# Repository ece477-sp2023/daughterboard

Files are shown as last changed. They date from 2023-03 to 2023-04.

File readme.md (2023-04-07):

# Things to change for v3

-   mosfet rotation
-   bulk capacitor on 2.5V plane
-   bulk capacitors directly on all regulator outputs
-   ftdi analog power from 5V
-   1.1V slow start from 3vi, not 3v3

# want to have

-   crystal for fpga?
-   crystal for ftdi?
    -   only if needed
-   indicator LEDs?
    -   power
    -   usb

# make sure before starting v3

-   ftdi chip works
    -   if not, have easy way to program flash

# notes for v3

-   8 layer board might give more space on top
-   don't need 1v1 slow start connected to both 3v3 and 2v5, just use 3v3
-   look at regulator stock for 5->3, don't know if footprint chosen is common / available

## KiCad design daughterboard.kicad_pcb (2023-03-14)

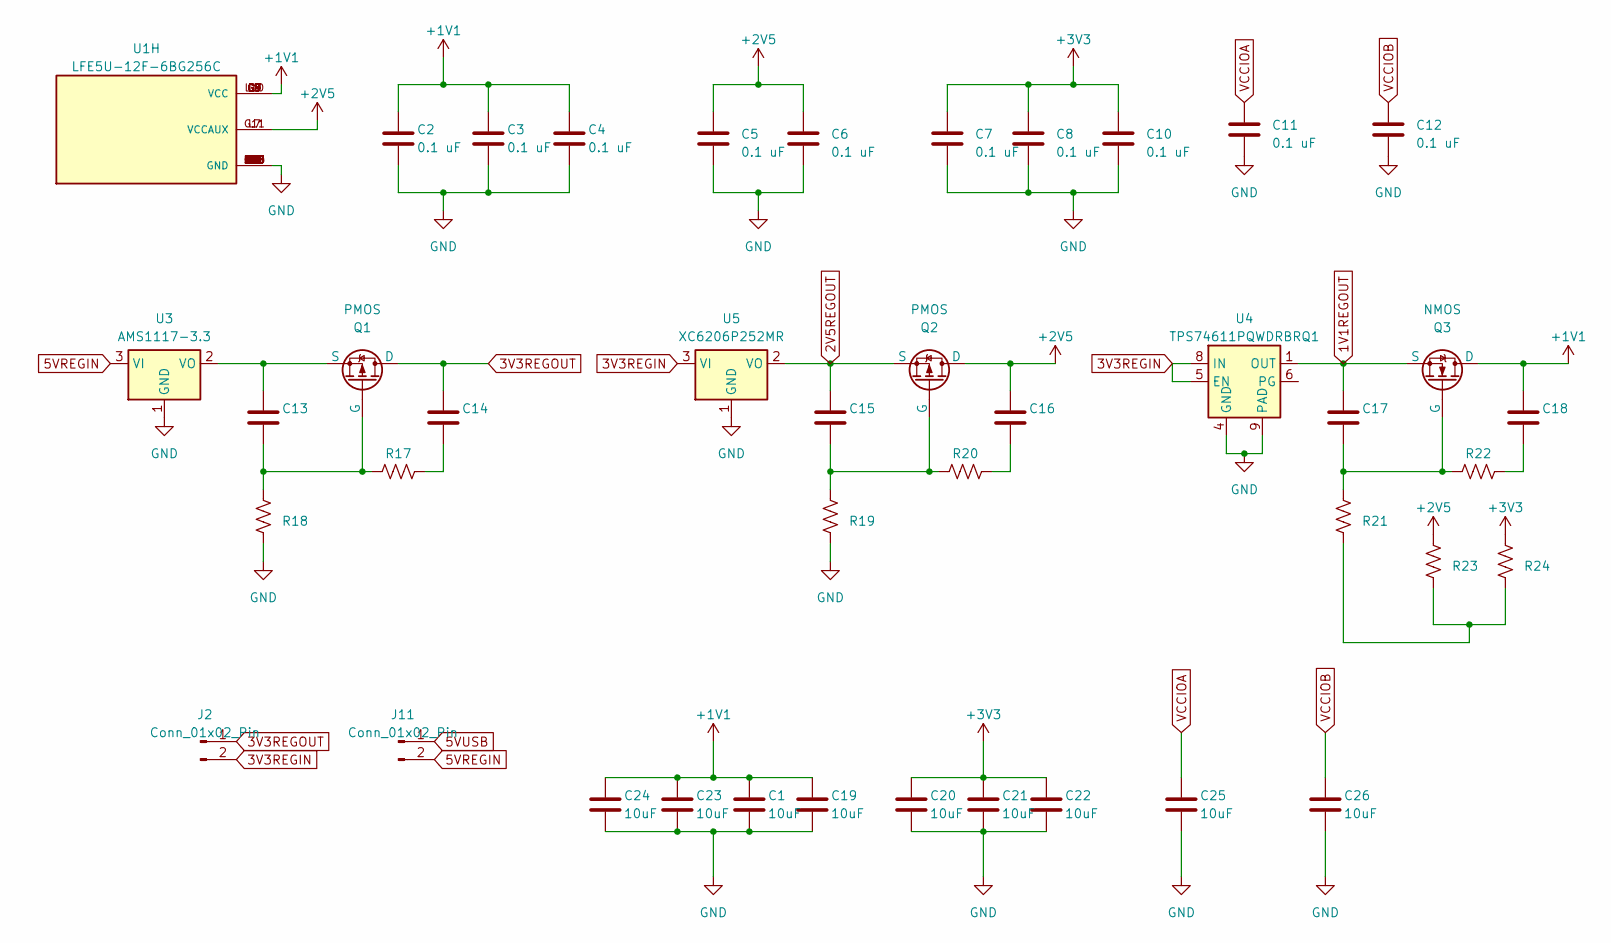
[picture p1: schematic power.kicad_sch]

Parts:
C1, C19, C20, C21, C22, C23, C24, C25, C26: 10uF; C_0805_2012Metric
C2, C3, C4, C5, C6, C7, C8, C10, C11, C12: 0.1 uF; C_0402_1005Metric
C13, C14, C15, C16, C17, C18: C_0805_2012Metric
J2, J11: Conn_01x02_Pin; PinHeader_1x02_P2.54mm_Vertical
Q1, Q2: PMOS; SOT-23-3
Q3: NMOS; SOT-23-3
R17, R18, R19, R20, R21, R22, R23, R24: R_0805_2012Metric
U1: LFE5U-12F-6BG256C; BGA256C80P16X16_1400X1400X170; PARTREV 2.0
U3: AMS1117-3.3; SOT-89-3
U4: TPS74611PQWDRBRQ1; Texas_S-PVSON-N8
U5: XC6206P252MR; SOT-23-3

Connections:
1V1REGOUT: C17.1, Q3.3 (S), U4.1 (OUT)
2V5REGOUT: C15.1, Q2.3 (S), U5.2 (VO)
3V3REGIN: J2.2, U4.5 (EN), U4.8 (IN), U5.3 (VI); also elsewhere on the board
3V3REGOUT: C14.1, J2.1, Q1.1 (D); also elsewhere on the board
5VREGIN: J11.2, U3.3 (VI); also elsewhere on the board
5VUSB: J11.1; also elsewhere on the board
+2V5: C5.1, C6.1, C16.1, Q2.1 (D), R23.2, U1.G11 (VCCAUX), U1.L7 (VCCAUX); also elsewhere on the board
GND: C1.2, C2.2, C3.2, C4.2, C5.2, C6.2, C7.2, C8.2, C10.2, C11.2, C12.2, C19.2, C20.2, C21.2, C22.2, C23.2, C24.2, C25.2, C26.2, R18.1, R19.1, U1.A1 (GND), U1.A16 (GND), U1.D2 (GND), U1.D15 (GND), U1.F8 (GND), U1.F9 (GND), U1.G8 (GND), U1.G10 (GND), U1.H1 (GND), U1.H8 (GND), U1.H9 (GND), U1.H10 (GND), U1.H16 (GND), U1.J8 (GND), U1.J9 (GND), U1.J10 (GND), U1.K6 (GND), U1.K7 (GND), U1.K8 (GND), U1.K9 (GND), U1.K10 (GND), U1.N2 (GND), U1.N15 (GND), U1.T1 (GND), U1.T5 (GND), U1.T12 (GND), U1.T16 (GND), U3.1 (GND), U4.4 (GND), U4.9 (PAD), U5.1 (GND); also elsewhere on the board
unnamed: C14.2, R17.1
unnamed: C16.2, R20.1
unnamed: C18.2, R22.1
unnamed: C13.2, Q1.2 (G), R17.2, R18.2
unnamed: C13.1, Q1.3 (S), U3.2 (VO)
unnamed: C15.2, Q2.2 (G), R19.2, R20.2
unnamed: C17.2, Q3.2 (G), R21.2, R22.2
unnamed: R21.1, R23.1, R24.1
VCCIOA: C11.1, C25.1; also elsewhere on the board
VCCIOB: C12.1, C26.1; also elsewhere on the board

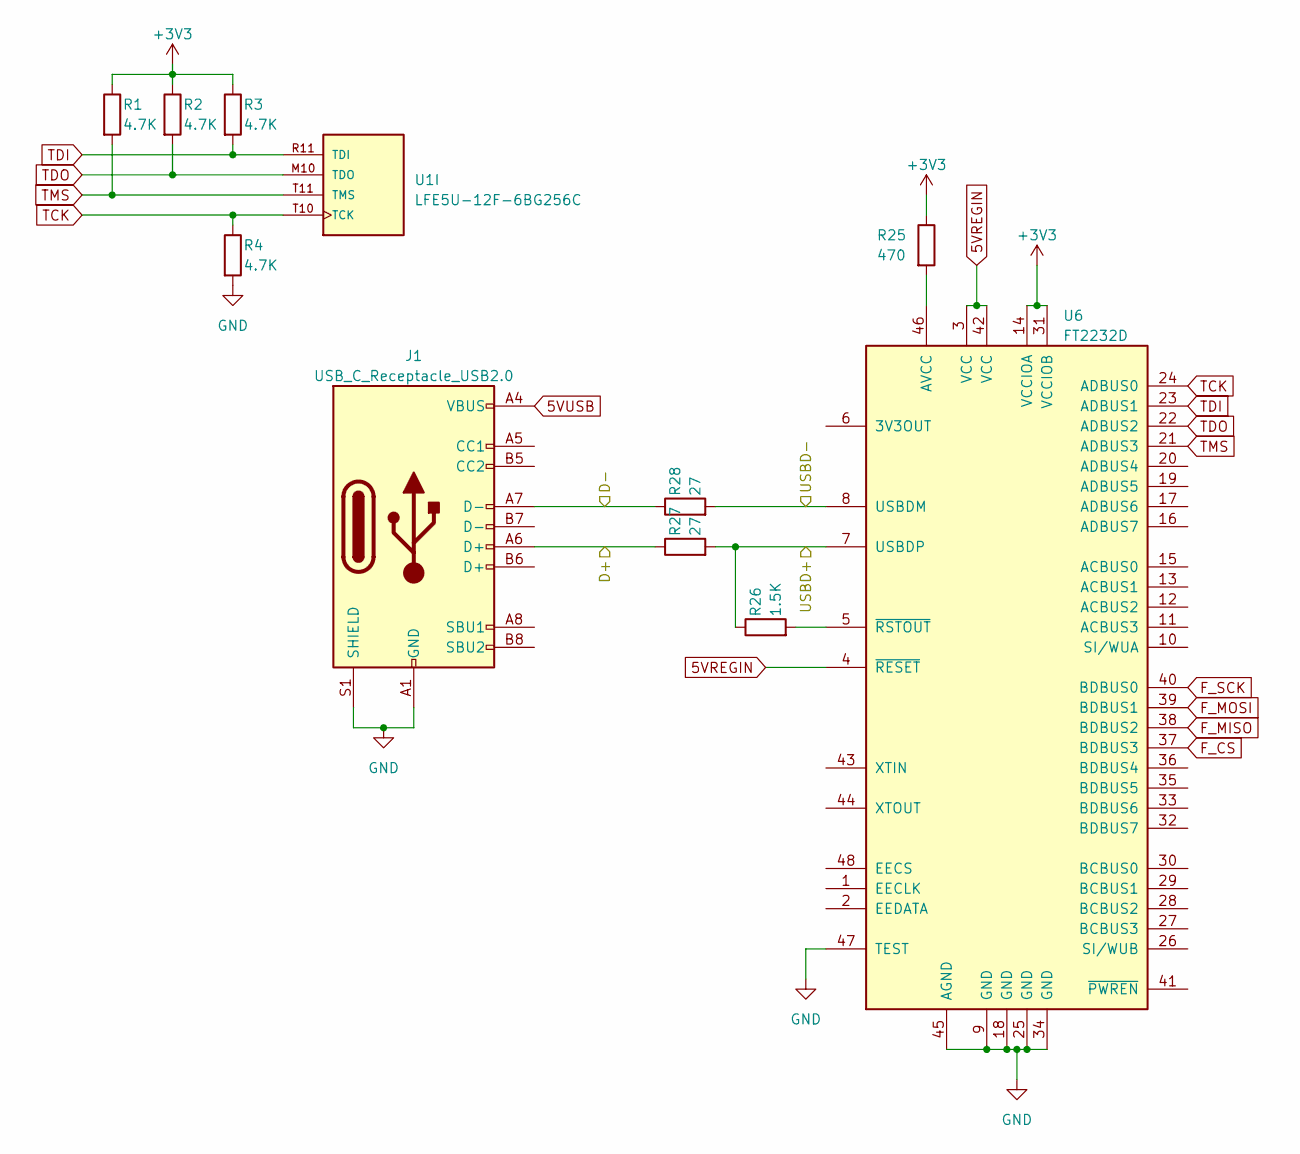
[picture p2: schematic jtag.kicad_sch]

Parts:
J1: USB_C_Receptacle_USB2.0; USB_C_GCT4105
R1, R2, R3, R4: 4.7K; R_0603_1608Metric
R25: 470; R_0603_1608Metric
R26: 1.5K; R_0603_1608Metric
R27, R28: 27; R_0603_1608Metric
U1: LFE5U-12F-6BG256C; BGA256C80P16X16_1400X1400X170; PARTREV 2.0
U6: FT2232D; LQFP-48_7x7mm_P0.5mm

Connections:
5VREGIN: U6.3 (VCC), U6.4 (~RESET), U6.42 (VCC); also elsewhere on the board
5VUSB: J1.A4 (VBUS), J1.A9 (VBUS), J1.B4 (VBUS), J1.B9 (VBUS); also elsewhere on the board
/JTAG/D+: J1.A6 (D+), R27.1
/JTAG/D-: J1.A7 (D-), R28.1
/JTAG/USBD+: R26.1, R27.2, U6.7 (USBDP)
/JTAG/USBD-: R28.2, U6.8 (USBDM)
F_CS: U6.37 (BDBUS3); also elsewhere on the board
F_MISO: U6.38 (BDBUS2); also elsewhere on the board
F_MOSI: U6.39 (BDBUS1); also elsewhere on the board
F_SCK: U6.40 (BDBUS0); also elsewhere on the board
GND: J1.A1 (GND), J1.A12 (GND), J1.B1 (GND), J1.B12 (GND), J1.S1 (SHIELD), R4.2, U6.9 (GND), U6.18 (GND), U6.25 (GND), U6.34 (GND), U6.45 (AGND), U6.47 (TEST); also elsewhere on the board
unnamed: R25.2, U6.46 (AVCC)
unnamed: R26.2, U6.5 (~RSTOUT)
TCK: R4.1, U1.T10 (TCK), U6.24 (ADBUS0); also elsewhere on the board
TDI: R3.2, U1.R11 (TDI), U6.23 (ADBUS1); also elsewhere on the board
TDO: R2.2, U1.M10 (TDO), U6.22 (ADBUS2); also elsewhere on the board
TMS: R1.2, U1.T11 (TMS), U6.21 (ADBUS3); also elsewhere on the board

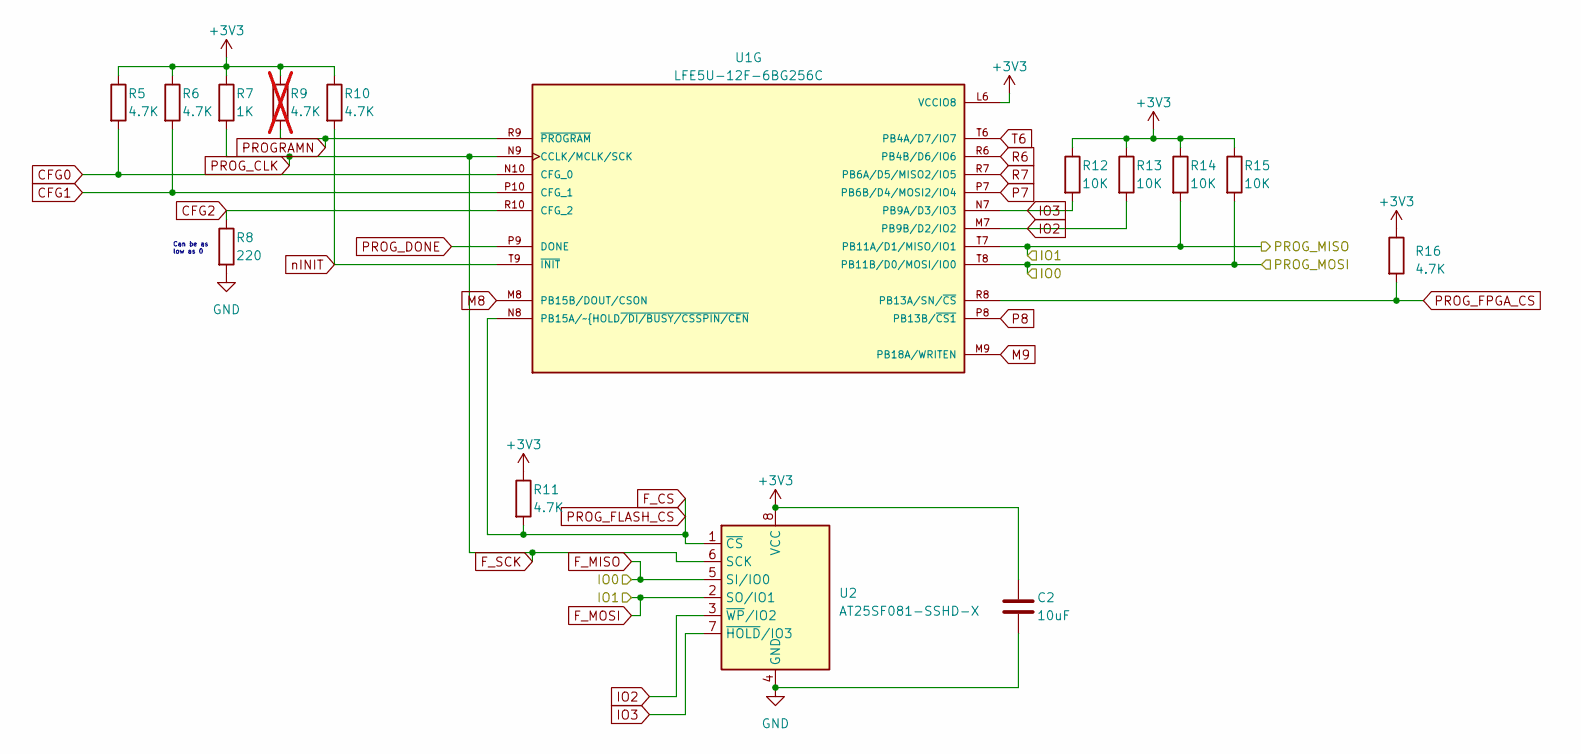
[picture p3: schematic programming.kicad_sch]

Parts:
C2: 10uF; C_0805_2012Metric
R5, R6, R10, R11, R16: 4.7K; R_0603_1608Metric
R7: 1K; R_0603_1608Metric
R8: 220; R_0603_1608Metric
R9: 4.7K; R_0603_1608Metric; not fitted
R12, R13, R14, R15: 10K; R_0603_1608Metric
U1: LFE5U-12F-6BG256C; BGA256C80P16X16_1400X1400X170; PARTREV 2.0
U2: AT25SF081-SSHD-X; SOIC-8_3.9x4.9mm_P1.27mm

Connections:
CFG0: R5.2, U1.N10 (CFG_0); also elsewhere on the board
CFG1: R6.2, U1.P10 (CFG_1); also elsewhere on the board
CFG2: R8.1, U1.R10 (CFG_2); also elsewhere on the board
F_CS: R11.2, U1.N8 (PB15A/~HOLD~{/DI/BUSY/CSSPIN/CEN), U2.1 (~CS); also elsewhere on the board
F_MISO: R15.2, U1.T8 (PB11B/D0/MOSI/IO0), U2.5 (SI/IO0); also elsewhere on the board
F_MOSI: R14.2, U1.T7 (PB11A/D1/MISO/IO1), U2.2 (SO/IO1); also elsewhere on the board
F_SCK: R7.2, U1.N9 (CCLK/MCLK/SCK), U2.6 (SCK); also elsewhere on the board
GND: C2.2, R8.2, U2.4 (GND); also elsewhere on the board
IO2: R13.2, U1.M7 (PB9B/D2/IO2), U2.3 (~WP/IO2); also elsewhere on the board
IO3: R12.2, U1.N7 (PB9A/D3/IO3), U2.7 (~HOLD/IO3); also elsewhere on the board
M8: U1.M8 (PB15B/DOUT/CSON); also elsewhere on the board
M9: U1.M9 (PB18A/WRITEN); also elsewhere on the board
P7: U1.P7 (PB6B/D4/MOSI2/IO4); also elsewhere on the board
P8: U1.P8 (PB13B/~CS1); also elsewhere on the board
PROGRAMN: R9.2, U1.R9 (~PROGRAM); also elsewhere on the board
PROG_DONE: U1.P9 (DONE); also elsewhere on the board
PROG_FPGA_CS: R16.2, U1.R8 (PB13A/SN/~CS); also elsewhere on the board
R6: U1.R6 (PB4B/D6/IO6); also elsewhere on the board
R7: U1.R7 (PB6A/D5/MISO2/IO5); also elsewhere on the board
T6: U1.T6 (PB4A/D7/IO7); also elsewhere on the board
nINIT: R10.2, U1.T9 (~INIT); also elsewhere on the board

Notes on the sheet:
Can be as low as 0

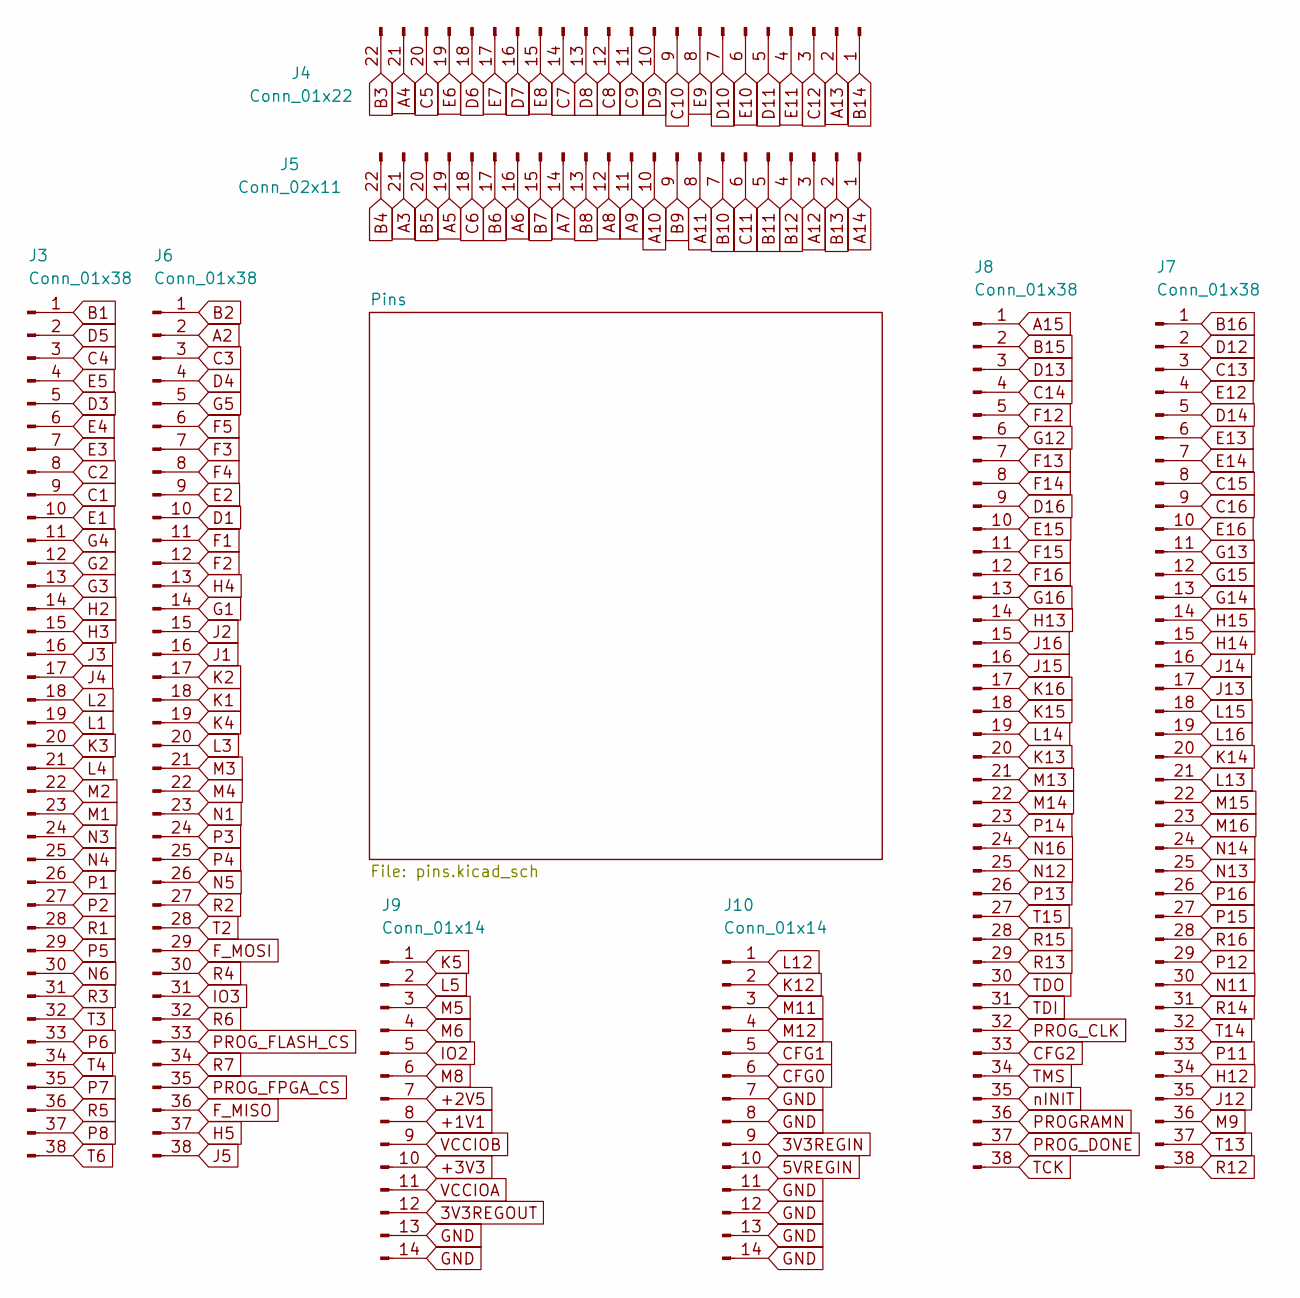
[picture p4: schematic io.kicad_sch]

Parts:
J3, J7: Conn_01x38; PinHeader_1x38_P1.27mm_Vertical
J4: Conn_01x22; PinHeader_1x22_P1.27mm_Vertical
J5: Conn_02x11; PinHeader_2x11_P2.54mm_Vertical
J6, J8: Conn_01x38; PinHeader_2x19_P2.54mm_Vertical
J9, J10: Conn_01x14; PinHeader_2x07_P2.54mm_Vertical

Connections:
3V3REGIN: J10.9; also elsewhere on the board
3V3REGOUT: J9.12; also elsewhere on the board
5VREGIN: J10.10; also elsewhere on the board
+2V5: J9.7; also elsewhere on the board
A2: J6.2; also elsewhere on the board
A3: J5.21; also elsewhere on the board
A4: J4.21; also elsewhere on the board
A5: J5.19; also elsewhere on the board
A6: J5.16; also elsewhere on the board
A7: J5.14; also elsewhere on the board
A8: J5.12; also elsewhere on the board
A9: J5.11; also elsewhere on the board
A10: J5.10; also elsewhere on the board
A11: J5.8; also elsewhere on the board
A12: J5.3; also elsewhere on the board
A13: J4.2; also elsewhere on the board
A14: J5.1; also elsewhere on the board
A15: J8.1; also elsewhere on the board
B1: J3.1; also elsewhere on the board
B2: J6.1; also elsewhere on the board
B3: J4.22; also elsewhere on the board
B4: J5.22; also elsewhere on the board
B5: J5.20; also elsewhere on the board
B6: J5.17; also elsewhere on the board
B7: J5.15; also elsewhere on the board
B8: J5.13; also elsewhere on the board
B9: J5.9; also elsewhere on the board
B10: J5.7; also elsewhere on the board
B11: J5.5; also elsewhere on the board
B12: J5.4; also elsewhere on the board
B13: J5.2; also elsewhere on the board
B14: J4.1; also elsewhere on the board
B15: J8.2; also elsewhere on the board
B16: J7.1; also elsewhere on the board
C1: J3.9; also elsewhere on the board
C2: J3.8; also elsewhere on the board
C3: J6.3; also elsewhere on the board
C4: J3.3; also elsewhere on the board
C5: J4.20; also elsewhere on the board
C6: J5.18; also elsewhere on the board
C7: J4.14; also elsewhere on the board
C8: J4.12; also elsewhere on the board
C9: J4.11; also elsewhere on the board
C10: J4.9; also elsewhere on the board
C11: J5.6; also elsewhere on the board
C12: J4.3; also elsewhere on the board
C13: J7.3; also elsewhere on the board
C14: J8.4; also elsewhere on the board
C15: J7.8; also elsewhere on the board
C16: J7.9; also elsewhere on the board
CFG0: J10.6; also elsewhere on the board
CFG1: J10.5; also elsewhere on the board
CFG2: J8.33; also elsewhere on the board
D1: J6.10; also elsewhere on the board
D3: J3.5; also elsewhere on the board
D4: J6.4; also elsewhere on the board
D5: J3.2; also elsewhere on the board
D6: J4.18; also elsewhere on the board
D7: J4.16; also elsewhere on the board
D8: J4.13; also elsewhere on the board
D9: J4.10; also elsewhere on the board
D10: J4.7; also elsewhere on the board
D11: J4.5; also elsewhere on the board
D12: J7.2; also elsewhere on the board
D13: J8.3; also elsewhere on the board
D14: J7.5; also elsewhere on the board
D16: J8.9; also elsewhere on the board
E1: J3.10; also elsewhere on the board
E2: J6.9; also elsewhere on the board
E3: J3.7; also elsewhere on the board
E4: J3.6; also elsewhere on the board
E5: J3.4; also elsewhere on the board
E6: J4.19; also elsewhere on the board
E7: J4.17; also elsewhere on the board
E8: J4.15; also elsewhere on the board
E9: J4.8; also elsewhere on the board
E10: J4.6; also elsewhere on the board
E11: J4.4; also elsewhere on the board
E12: J7.4; also elsewhere on the board
E13: J7.6; also elsewhere on the board
E14: J7.7; also elsewhere on the board
E15: J8.10; also elsewhere on the board
E16: J7.10; also elsewhere on the board
F1: J6.11; also elsewhere on the board
F2: J6.12; also elsewhere on the board
F3: J6.7; also elsewhere on the board
F4: J6.8; also elsewhere on the board
F5: J6.6; also elsewhere on the board
F12: J8.5; also elsewhere on the board
F13: J8.7; also elsewhere on the board
F14: J8.8; also elsewhere on the board
F15: J8.11; also elsewhere on the board
F16: J8.12; also elsewhere on the board
F_CS: J6.33; also elsewhere on the board
F_MISO: J6.36; also elsewhere on the board
F_MOSI: J6.29; also elsewhere on the board
F_SCK: J8.32; also elsewhere on the board
G1: J6.14; also elsewhere on the board
G2: J3.12; also elsewhere on the board
G3: J3.13; also elsewhere on the board
G4: J3.11; also elsewhere on the board
G5: J6.5; also elsewhere on the board
G12: J8.6; also elsewhere on the board
G13: J7.11; also elsewhere on the board
G14: J7.13; also elsewhere on the board
G15: J7.12; also elsewhere on the board
G16: J8.13; also elsewhere on the board
GND: J9.13, J9.14, J10.7, J10.8, J10.11, J10.12, J10.13, J10.14; also elsewhere on the board
H2: J3.14; also elsewhere on the board
H3: J3.15; also elsewhere on the board
H4: J6.13; also elsewhere on the board
H5: J6.37; also elsewhere on the board
H12: J7.34; also elsewhere on the board
H13: J8.14; also elsewhere on the board
H14: J7.15; also elsewhere on the board
H15: J7.14; also elsewhere on the board
IO2: J9.5; also elsewhere on the board
IO3: J6.31; also elsewhere on the board
J1: J6.16; also elsewhere on the board
J2: J6.15; also elsewhere on the board
J3: J3.16; also elsewhere on the board
J4: J3.17; also elsewhere on the board
J5: J6.38; also elsewhere on the board
J12: J7.35; also elsewhere on the board
J13: J7.17; also elsewhere on the board
J14: J7.16; also elsewhere on the board
J15: J8.16; also elsewhere on the board
J16: J8.15; also elsewhere on the board
K1: J6.18; also elsewhere on the board
K2: J6.17; also elsewhere on the board
K3: J3.20; also elsewhere on the board
K4: J6.19; also elsewhere on the board
K5: J9.1; also elsewhere on the board
K12: J10.2; also elsewhere on the board
K13: J8.20; also elsewhere on the board
K14: J7.20; also elsewhere on the board
K15: J8.18; also elsewhere on the board
K16: J8.17; also elsewhere on the board
L1: J3.19; also elsewhere on the board
L2: J3.18; also elsewhere on the board
L3: J6.20; also elsewhere on the board
L4: J3.21; also elsewhere on the board
L5: J9.2; also elsewhere on the board
L12: J10.1; also elsewhere on the board
L13: J7.21; also elsewhere on the board
L14: J8.19; also elsewhere on the board
L15: J7.18; also elsewhere on the board
L16: J7.19; also elsewhere on the board
M1: J3.23; also elsewhere on the board
M2: J3.22; also elsewhere on the board
M3: J6.21; also elsewhere on the board
M4: J6.22; also elsewhere on the board
M5: J9.3; also elsewhere on the board
M6: J9.4; also elsewhere on the board
M8: J9.6; also elsewhere on the board
M9: J7.36; also elsewhere on the board
M11: J10.3; also elsewhere on the board
M12: J10.4; also elsewhere on the board
M13: J8.21; also elsewhere on the board
M14: J8.22; also elsewhere on the board
M15: J7.22; also elsewhere on the board
M16: J7.23; also elsewhere on the board
N1: J6.23; also elsewhere on the board
N3: J3.24; also elsewhere on the board
N4: J3.25; also elsewhere on the board
N5: J6.26; also elsewhere on the board
N6: J3.30; also elsewhere on the board
N11: J7.30; also elsewhere on the board
N12: J8.25; also elsewhere on the board
N13: J7.25; also elsewhere on the board
N14: J7.24; also elsewhere on the board
N16: J8.24; also elsewhere on the board
P1: J3.26; also elsewhere on the board
P2: J3.27; also elsewhere on the board
P3: J6.24; also elsewhere on the board
P4: J6.25; also elsewhere on the board
P5: J3.29; also elsewhere on the board
P6: J3.33; also elsewhere on the board
P7: J3.35; also elsewhere on the board
P8: J3.37; also elsewhere on the board
P11: J7.33; also elsewhere on the board
P12: J7.29; also elsewhere on the board
P13: J8.26; also elsewhere on the board
P14: J8.23; also elsewhere on the board
P15: J7.27; also elsewhere on the board
P16: J7.26; also elsewhere on the board
PROGRAMN: J8.36; also elsewhere on the board
PROG_DONE: J8.37; also elsewhere on the board
PROG_FPGA_CS: J6.35; also elsewhere on the board
R1: J3.28; also elsewhere on the board
R2: J6.27; also elsewhere on the board
R3: J3.31; also elsewhere on the board
R4: J6.30; also elsewhere on the board
R5: J3.36; also elsewhere on the board
R6: J6.32; also elsewhere on the board
R7: J6.34; also elsewhere on the board
R12: J7.38; also elsewhere on the board
R13: J8.29; also elsewhere on the board
R14: J7.31; also elsewhere on the board
R15: J8.28; also elsewhere on the board
R16: J7.28; also elsewhere on the board
T2: J6.28; also elsewhere on the board
T3: J3.32; also elsewhere on the board
T4: J3.34; also elsewhere on the board
T6: J3.38; also elsewhere on the board
T13: J7.37; also elsewhere on the board
T14: J7.32; also elsewhere on the board
T15: J8.27; also elsewhere on the board
TCK: J8.38; also elsewhere on the board
TDI: J8.31; also elsewhere on the board
TDO: J8.30; also elsewhere on the board
TMS: J8.34; also elsewhere on the board
VCCIOA: J9.11; also elsewhere on the board
VCCIOB: J9.9; also elsewhere on the board
nINIT: J8.35; also elsewhere on the board

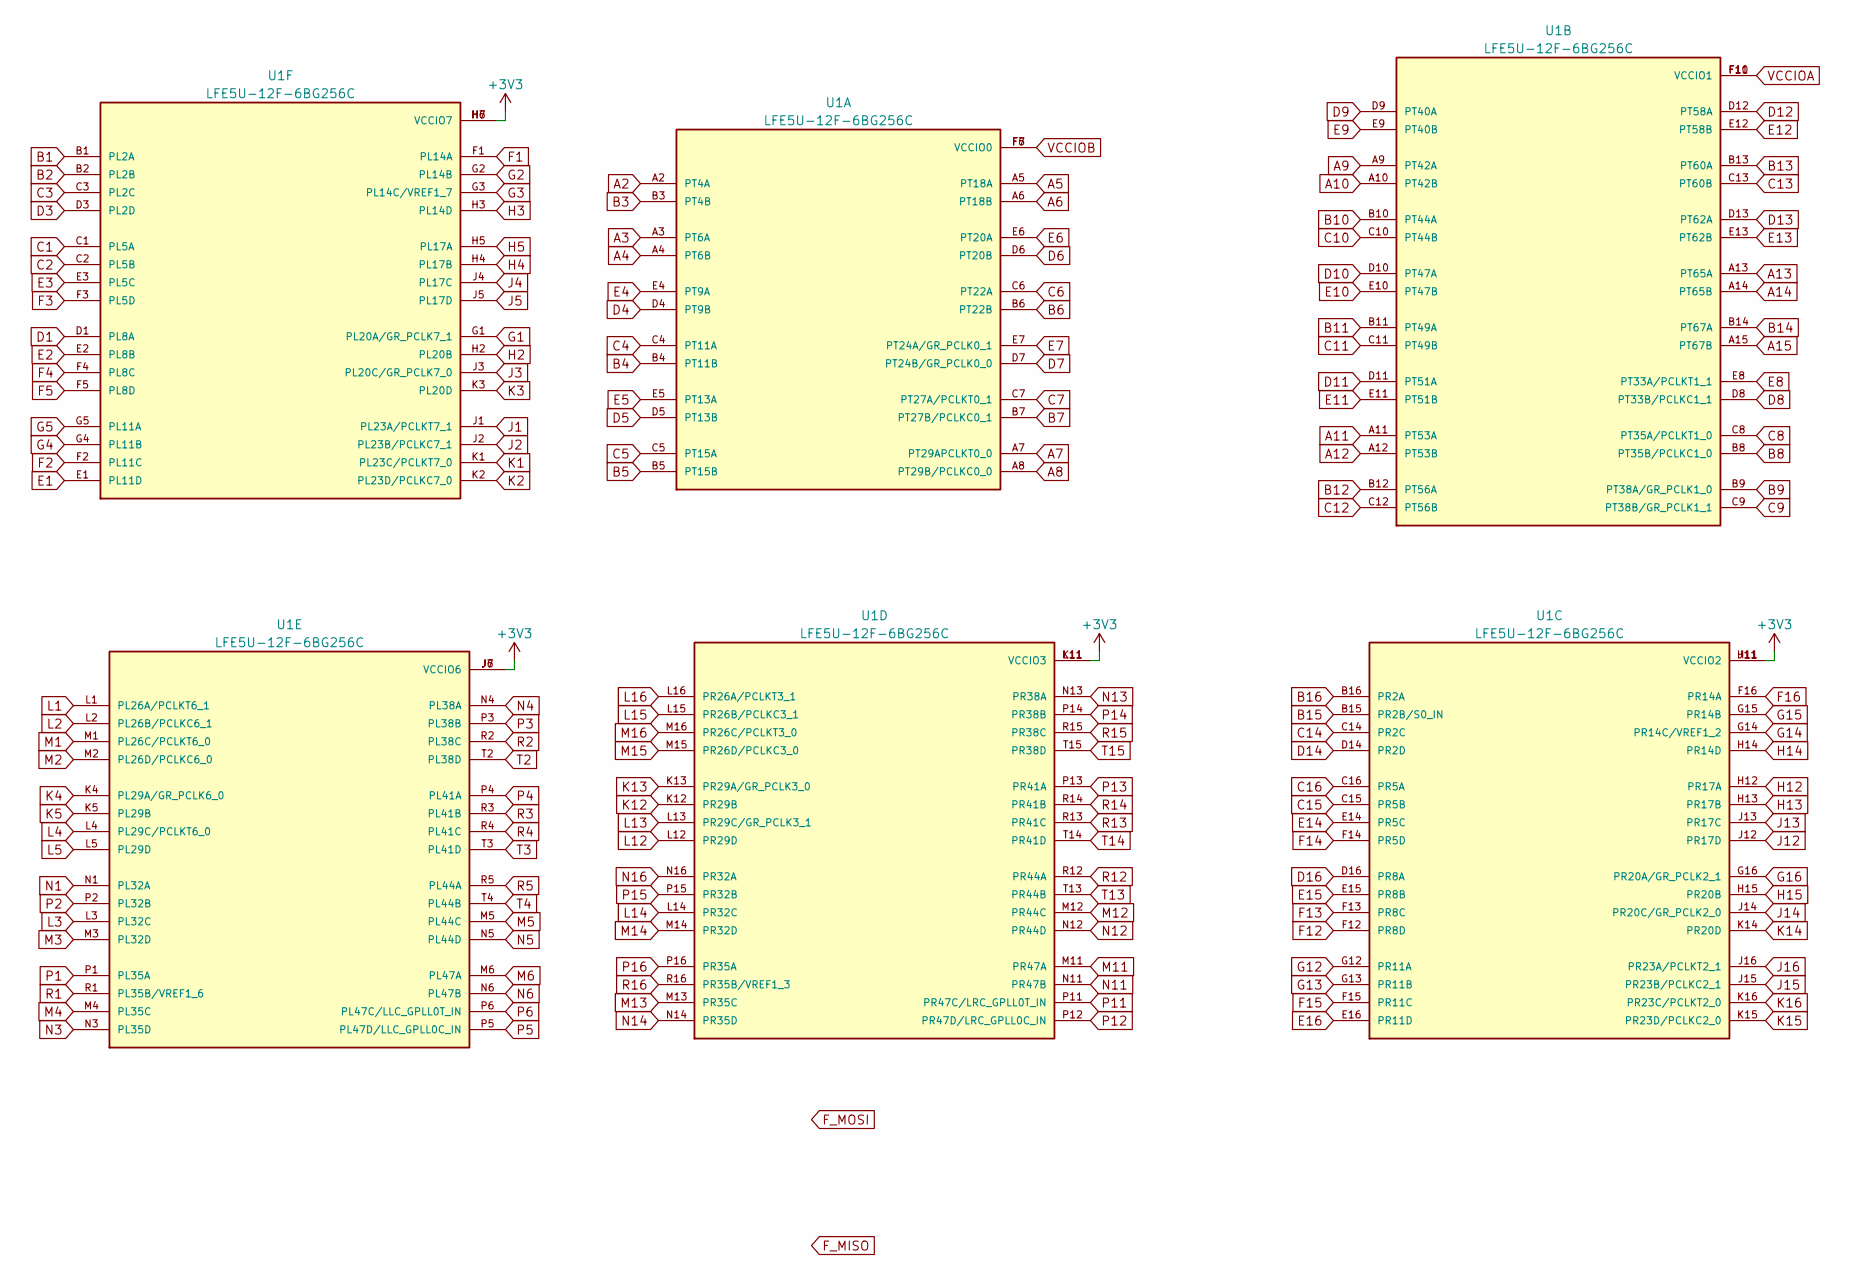
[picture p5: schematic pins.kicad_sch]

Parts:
U1: LFE5U-12F-6BG256C; BGA256C80P16X16_1400X1400X170; PARTREV 2.0

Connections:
A2: U1.A2 (PT4A); also elsewhere on the board
A3: U1.A3 (PT6A); also elsewhere on the board
A4: U1.A4 (PT6B); also elsewhere on the board
A5: U1.A5 (PT18A); also elsewhere on the board
A6: U1.A6 (PT18B); also elsewhere on the board
A7: U1.A7 (PT29APCLKT0_0); also elsewhere on the board
A8: U1.A8 (PT29B/PCLKC0_0); also elsewhere on the board
A9: U1.A9 (PT42A); also elsewhere on the board
A10: U1.A10 (PT42B); also elsewhere on the board
A11: U1.A11 (PT53A); also elsewhere on the board
A12: U1.A12 (PT53B); also elsewhere on the board
A13: U1.A13 (PT65A); also elsewhere on the board
A14: U1.A14 (PT65B); also elsewhere on the board
A15: U1.A15 (PT67B); also elsewhere on the board
B1: U1.B1 (PL2A); also elsewhere on the board
B2: U1.B2 (PL2B); also elsewhere on the board
B3: U1.B3 (PT4B); also elsewhere on the board
B4: U1.B4 (PT11B); also elsewhere on the board
B5: U1.B5 (PT15B); also elsewhere on the board
B6: U1.B6 (PT22B); also elsewhere on the board
B7: U1.B7 (PT27B/PCLKC0_1); also elsewhere on the board
B8: U1.B8 (PT35B/PCLKC1_0); also elsewhere on the board
B9: U1.B9 (PT38A/GR_PCLK1_0); also elsewhere on the board
B10: U1.B10 (PT44A); also elsewhere on the board
B11: U1.B11 (PT49A); also elsewhere on the board
B12: U1.B12 (PT56A); also elsewhere on the board
B13: U1.B13 (PT60A); also elsewhere on the board
B14: U1.B14 (PT67A); also elsewhere on the board
B15: U1.B15 (PR2B/S0_IN); also elsewhere on the board
B16: U1.B16 (PR2A); also elsewhere on the board
C1: U1.C1 (PL5A); also elsewhere on the board
C2: U1.C2 (PL5B); also elsewhere on the board
C3: U1.C3 (PL2C); also elsewhere on the board
C4: U1.C4 (PT11A); also elsewhere on the board
C5: U1.C5 (PT15A); also elsewhere on the board
C6: U1.C6 (PT22A); also elsewhere on the board
C7: U1.C7 (PT27A/PCLKT0_1); also elsewhere on the board
C8: U1.C8 (PT35A/PCLKT1_0); also elsewhere on the board
C9: U1.C9 (PT38B/GR_PCLK1_1); also elsewhere on the board
C10: U1.C10 (PT44B); also elsewhere on the board
C11: U1.C11 (PT49B); also elsewhere on the board
C12: U1.C12 (PT56B); also elsewhere on the board
C13: U1.C13 (PT60B); also elsewhere on the board
C14: U1.C14 (PR2C); also elsewhere on the board
C15: U1.C15 (PR5B); also elsewhere on the board
C16: U1.C16 (PR5A); also elsewhere on the board
D1: U1.D1 (PL8A); also elsewhere on the board
D3: U1.D3 (PL2D); also elsewhere on the board
D4: U1.D4 (PT9B); also elsewhere on the board
D5: U1.D5 (PT13B); also elsewhere on the board
D6: U1.D6 (PT20B); also elsewhere on the board
D7: U1.D7 (PT24B/GR_PCLK0_0); also elsewhere on the board
D8: U1.D8 (PT33B/PCLKC1_1); also elsewhere on the board
D9: U1.D9 (PT40A); also elsewhere on the board
D10: U1.D10 (PT47A); also elsewhere on the board
D11: U1.D11 (PT51A); also elsewhere on the board
D12: U1.D12 (PT58A); also elsewhere on the board
D13: U1.D13 (PT62A); also elsewhere on the board
D14: U1.D14 (PR2D); also elsewhere on the board
D16: U1.D16 (PR8A); also elsewhere on the board
E1: U1.E1 (PL11D); also elsewhere on the board
E2: U1.E2 (PL8B); also elsewhere on the board
E3: U1.E3 (PL5C); also elsewhere on the board
E4: U1.E4 (PT9A); also elsewhere on the board
E5: U1.E5 (PT13A); also elsewhere on the board
E6: U1.E6 (PT20A); also elsewhere on the board
E7: U1.E7 (PT24A/GR_PCLK0_1); also elsewhere on the board
E8: U1.E8 (PT33A/PCLKT1_1); also elsewhere on the board
E9: U1.E9 (PT40B); also elsewhere on the board
E10: U1.E10 (PT47B); also elsewhere on the board
E11: U1.E11 (PT51B); also elsewhere on the board
E12: U1.E12 (PT58B); also elsewhere on the board
E13: U1.E13 (PT62B); also elsewhere on the board
E14: U1.E14 (PR5C); also elsewhere on the board
E15: U1.E15 (PR8B); also elsewhere on the board
E16: U1.E16 (PR11D); also elsewhere on the board
F1: U1.F1 (PL14A); also elsewhere on the board
F2: U1.F2 (PL11C); also elsewhere on the board
F3: U1.F3 (PL5D); also elsewhere on the board
F4: U1.F4 (PL8C); also elsewhere on the board
F5: U1.F5 (PL8D); also elsewhere on the board
F12: U1.F12 (PR8D); also elsewhere on the board
F13: U1.F13 (PR8C); also elsewhere on the board
F14: U1.F14 (PR5D); also elsewhere on the board
F15: U1.F15 (PR11C); also elsewhere on the board
F16: U1.F16 (PR14A); also elsewhere on the board
G1: U1.G1 (PL20A/GR_PCLK7_1); also elsewhere on the board
G2: U1.G2 (PL14B); also elsewhere on the board
G3: U1.G3 (PL14C/VREF1_7); also elsewhere on the board
G4: U1.G4 (PL11B); also elsewhere on the board
G5: U1.G5 (PL11A); also elsewhere on the board
G12: U1.G12 (PR11A); also elsewhere on the board
G13: U1.G13 (PR11B); also elsewhere on the board
G14: U1.G14 (PR14C/VREF1_2); also elsewhere on the board
G15: U1.G15 (PR14B); also elsewhere on the board
G16: U1.G16 (PR20A/GR_PCLK2_1); also elsewhere on the board
H2: U1.H2 (PL20B); also elsewhere on the board
H3: U1.H3 (PL14D); also elsewhere on the board
H4: U1.H4 (PL17B); also elsewhere on the board
H5: U1.H5 (PL17A); also elsewhere on the board
H12: U1.H12 (PR17A); also elsewhere on the board
H13: U1.H13 (PR17B); also elsewhere on the board
H14: U1.H14 (PR14D); also elsewhere on the board
H15: U1.H15 (PR20B); also elsewhere on the board
J1: U1.J1 (PL23A/PCLKT7_1); also elsewhere on the board
J2: U1.J2 (PL23B/PCLKC7_1); also elsewhere on the board
J3: U1.J3 (PL20C/GR_PCLK7_0); also elsewhere on the board
J4: U1.J4 (PL17C); also elsewhere on the board
J5: U1.J5 (PL17D); also elsewhere on the board
J12: U1.J12 (PR17D); also elsewhere on the board
J13: U1.J13 (PR17C); also elsewhere on the board
J14: U1.J14 (PR20C/GR_PCLK2_0); also elsewhere on the board
J15: U1.J15 (PR23B/PCLKC2_1); also elsewhere on the board
J16: U1.J16 (PR23A/PCLKT2_1); also elsewhere on the board
K1: U1.K1 (PL23C/PCLKT7_0); also elsewhere on the board
K2: U1.K2 (PL23D/PCLKC7_0); also elsewhere on the board
K3: U1.K3 (PL20D); also elsewhere on the board
K4: U1.K4 (PL29A/GR_PCLK6_0); also elsewhere on the board
K5: U1.K5 (PL29B); also elsewhere on the board
K12: U1.K12 (PR29B); also elsewhere on the board
K13: U1.K13 (PR29A/GR_PCLK3_0); also elsewhere on the board
K14: U1.K14 (PR20D); also elsewhere on the board
K15: U1.K15 (PR23D/PCLKC2_0); also elsewhere on the board
K16: U1.K16 (PR23C/PCLKT2_0); also elsewhere on the board
L1: U1.L1 (PL26A/PCLKT6_1); also elsewhere on the board
L2: U1.L2 (PL26B/PCLKC6_1); also elsewhere on the board
L3: U1.L3 (PL32C); also elsewhere on the board
L4: U1.L4 (PL29C/PCLKT6_0); also elsewhere on the board
L5: U1.L5 (PL29D); also elsewhere on the board
L12: U1.L12 (PR29D); also elsewhere on the board
L13: U1.L13 (PR29C/GR_PCLK3_1); also elsewhere on the board
L14: U1.L14 (PR32C); also elsewhere on the board
L15: U1.L15 (PR26B/PCLKC3_1); also elsewhere on the board
L16: U1.L16 (PR26A/PCLKT3_1); also elsewhere on the board
M1: U1.M1 (PL26C/PCLKT6_0); also elsewhere on the board
M2: U1.M2 (PL26D/PCLKC6_0); also elsewhere on the board
M3: U1.M3 (PL32D); also elsewhere on the board
M4: U1.M4 (PL35C); also elsewhere on the board
M5: U1.M5 (PL44C); also elsewhere on the board
M6: U1.M6 (PL47A); also elsewhere on the board
M11: U1.M11 (PR47A); also elsewhere on the board
M12: U1.M12 (PR44C); also elsewhere on the board
M13: U1.M13 (PR35C); also elsewhere on the board
M14: U1.M14 (PR32D); also elsewhere on the board
M15: U1.M15 (PR26D/PCLKC3_0); also elsewhere on the board
M16: U1.M16 (PR26C/PCLKT3_0); also elsewhere on the board
N1: U1.N1 (PL32A); also elsewhere on the board
N3: U1.N3 (PL35D); also elsewhere on the board
N4: U1.N4 (PL38A); also elsewhere on the board
N5: U1.N5 (PL44D); also elsewhere on the board
N6: U1.N6 (PL47B); also elsewhere on the board
N11: U1.N11 (PR47B); also elsewhere on the board
N12: U1.N12 (PR44D); also elsewhere on the board
N13: U1.N13 (PR38A); also elsewhere on the board
N14: U1.N14 (PR35D); also elsewhere on the board
N16: U1.N16 (PR32A); also elsewhere on the board
P1: U1.P1 (PL35A); also elsewhere on the board
P2: U1.P2 (PL32B); also elsewhere on the board
P3: U1.P3 (PL38B); also elsewhere on the board
P4: U1.P4 (PL41A); also elsewhere on the board
P5: U1.P5 (PL47D/LLC_GPLL0C_IN); also elsewhere on the board
P6: U1.P6 (PL47C/LLC_GPLL0T_IN); also elsewhere on the board
P11: U1.P11 (PR47C/LRC_GPLL0T_IN); also elsewhere on the board
P12: U1.P12 (PR47D/LRC_GPLL0C_IN); also elsewhere on the board
P13: U1.P13 (PR41A); also elsewhere on the board
P14: U1.P14 (PR38B); also elsewhere on the board
P15: U1.P15 (PR32B); also elsewhere on the board
P16: U1.P16 (PR35A); also elsewhere on the board
R1: U1.R1 (PL35B/VREF1_6); also elsewhere on the board
R2: U1.R2 (PL38C); also elsewhere on the board
R3: U1.R3 (PL41B); also elsewhere on the board
R4: U1.R4 (PL41C); also elsewhere on the board
R5: U1.R5 (PL44A); also elsewhere on the board
R12: U1.R12 (PR44A); also elsewhere on the board
R13: U1.R13 (PR41C); also elsewhere on the board
R14: U1.R14 (PR41B); also elsewhere on the board
R15: U1.R15 (PR38C); also elsewhere on the board
R16: U1.R16 (PR35B/VREF1_3); also elsewhere on the board
T2: U1.T2 (PL38D); also elsewhere on the board
T3: U1.T3 (PL41D); also elsewhere on the board
T4: U1.T4 (PL44B); also elsewhere on the board
T13: U1.T13 (PR44B); also elsewhere on the board
T14: U1.T14 (PR41D); also elsewhere on the board
T15: U1.T15 (PR38D); also elsewhere on the board
VCCIOA: U1.F10 (VCCIO1), U1.F11 (VCCIO1); also elsewhere on the board
VCCIOB: U1.F6 (VCCIO0), U1.F7 (VCCIO0); also elsewhere on the board

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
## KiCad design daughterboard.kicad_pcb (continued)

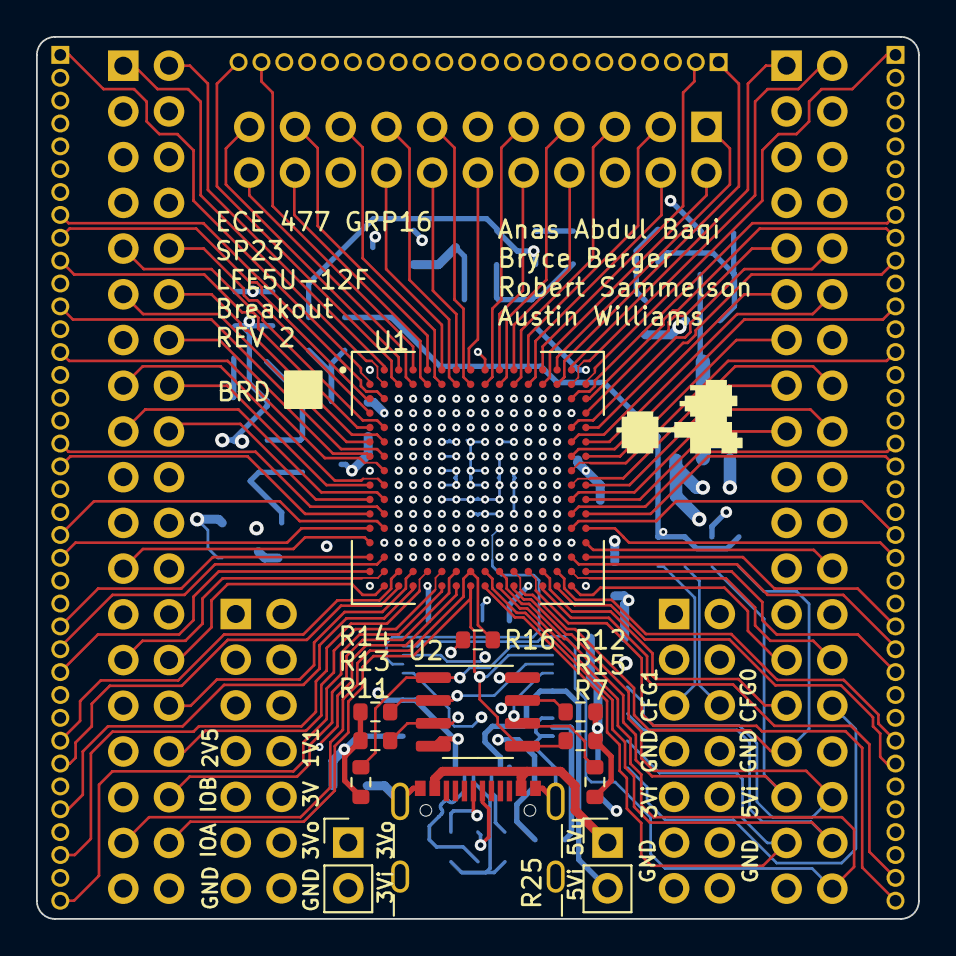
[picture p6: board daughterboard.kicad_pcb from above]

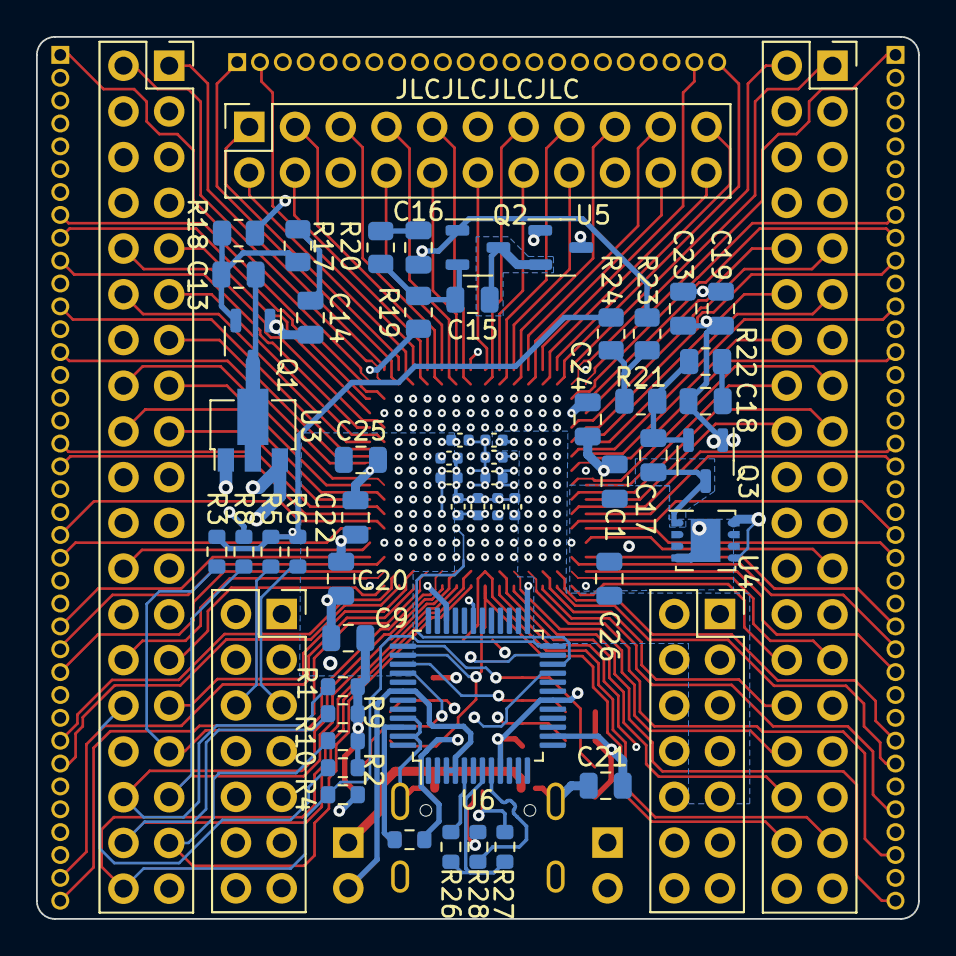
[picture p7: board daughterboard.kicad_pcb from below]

Board: 6 copper layers, 49.0 x 49.0 mm, 74 parts (54 on the bottom side), 234 nets.

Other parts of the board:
C9: 10uF; C_0805_2012Metric

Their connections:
GND: C9.2; also elsewhere on the board

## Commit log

2023-02-18 Basic breakout routing complete
    [daughterboard.kicad_pcb, daughterboard.kicad_sch, io.kicad_sch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]
2023-02-25 Small routing tweaks, add breakout to schematic
    [daughterboard.kicad_pcb, daughterboard.kicad_sch, io.kicad_sch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]
2023-02-26 Route flash + jtag resistors
    [daughterboard.kicad_pcb, jtag.kicad_sch, pins.kicad_sch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]
2023-02-27 Route power
    [daughterboard.kicad_pcb, daughterboard.kicad_sch, power.kicad_sch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]
2023-02-27 Move programming pins to 100 mil headers
    [daughterboard.kicad_pcb, io.kicad_sch, programming.kicad_sch]
2023-02-27 Schematic tweaks for readability
    [io.kicad_sch, power.kicad_sch]
2023-03-12 Route power, FTDI chip
    [daughterboard.kicad_pcb, daughterboard.kicad_sch, io.kicad_sch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]
2023-03-13 Silkscreen, more power
    [daughterboard.kicad_pcb, power.kicad_sch]
2023-03-14 Fix hole clearance and add fillet
    [daughterboard.kicad_pcb]
2023-04-07 Values for slow start circuitry
    [power.kicad_sch]
